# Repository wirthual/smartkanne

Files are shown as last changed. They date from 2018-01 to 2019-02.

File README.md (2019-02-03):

# SmartKanne [smaːɐ̯tˈkanə]

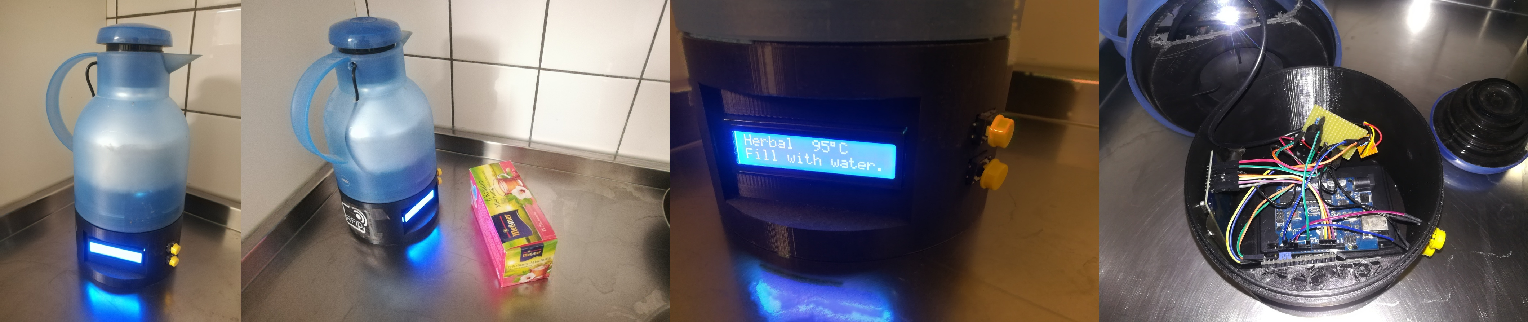
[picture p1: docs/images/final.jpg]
final image sprite


### 1. Introduction
This project was created for the Ubiquitous Computing Course at the Karlsruhe Institute of Technology. The goal of this course is to learn about the development process of a smart appliance. Topics covered in this course are techniques for finding a good idea, analyse your potential customers, sketching methods as well as the technical part like hardware including sensors, actuators and knowledge about arduino.

#### 1.1 Project structure
| Folder | Content |
|:---|:--- |
| README.md | This file. Information about the project in github flavoured markup ([GFM](https://github.github.com/gfm/) )|
| src/ | Contains source code for uploading to arduino|
| docs/schema/ | Contains schema of the electrocins and bill of material. Created with [Fritzing](http://fritzing.org/home/) |
| docs/sketches/ |Contains images of the sketches that were made in the project planning |
|docs/state_diagram/| Contains the state diagram of the finite state machine used in this project. Created with [Dia](https://wiki.gnome.org/Apps/Dia) 
| docs/housing/ | Contains a enlargement for the housing of the tea pot. The .slt file can be printed with a 3D-printer. Created with [FreeCAD](https://www.freecadweb.org/?lang=de).  Also an [image](http://www.rfidsign.eu/html/graphics.html) to indicate the RFID capability is included.  |
| docs/misc/ | Contains a Business model plan as well as a cost estimation made with COSYSMO. 

### 2. Project idea
The idea for this problem came to me during the winter months drinking a lot of tea. However, every time I made a tea I forgot to take the tea bags out of the pot so very often the tea became bitter in the end.
I want to solve this problem by developing this SmartKanne. This device should help me not to forget about my tea. Also it should be able to give me instructions about the right temperature and time for each tea to get the best possible result when steeping tea.

### 3. Requirements
Here I list the basic requierements SmartKanne should be able to cover:

| Requirement | Description |
|:---|:--- |
|Tea selection|The user should be able to select the type of tea he wants to make|
|Tea information|Depending on the type of tea, SmartKanne should know the recommended temperature as well as the steep time |
|Notification|If the tea is ready to drink, SmartKanne should be able to notify to the user |
|Monitor process|In order to let the user know about the progress of his tea, SmartKanne should be able to give feedback to the user about the process|
|Mobile|The device should be able to be carried around while the tea is in progress, so there is no need to wait at a certain point.|

### 4. Designs
In order to cover the features from section 3, SmartKanne needs some additional hardware to fullfill the requierements. In this section I show you some sketches I made in the development process.

#### 4.1 Use Smartphone as user interface
One idea to satisfy the requirements is to control SmartKanne by a smartphone which can communicate over bluetooth low energy or  wifi or something similar. This would have the advantage to allow a lot of settings for the smart kanne, since you have an full interface with all possible UI elements.

sketch smartphone

#### 4.2 Standalone
Onaother possibility to create the user interface for SmartKanne is to use additional hardware. This design allows the gadget to be used independently from other devices and lowers the complexity of usage. Furthermore external sources of errors are excluded. For the power supply there has to be an battery pack included to ensure a convenient usage of the device.

sketch standalone

#### 4.3 Base station
Design number 3 is an approach without external devices as well. However, the idea here is to put all the electronics in an base station where you can put an pot that is then connected automatically. This way multiple pots could be used with one base station(multi user support with multiple pots). The pot would then just include the temerature sensor which would be connected when the pot is put into the station. The disadvantage is that you have to wait till the tea is done to take the pot with you and leave the station behind. Then the base station could be powered by an outlet since it will be stationary anyway. 

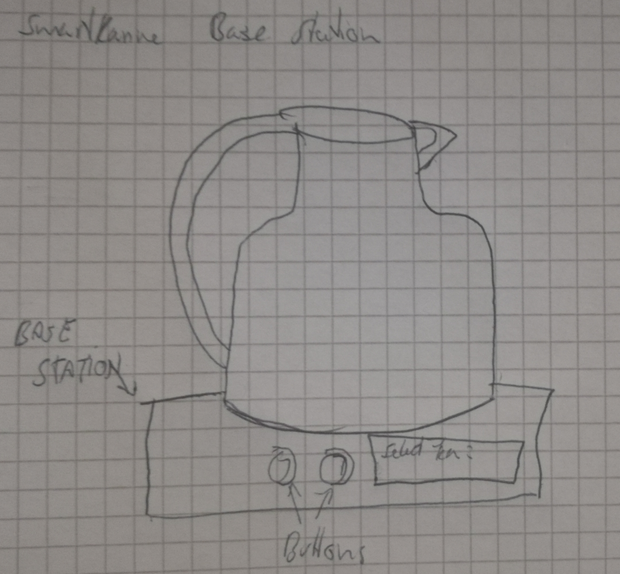
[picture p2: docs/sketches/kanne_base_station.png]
sketch base station


### 5. Design Decision 
In order to build a n appliance the approch number 4.2 seems the best choice in order to have a big impact in the process of making tea. The limitation of user interaction prevents the device from getting to complex and developing some kind of “feature creep”. 
The usage of an additional smart phone brings a lot of overhead an in total two devices are needed for the process of making tea. The idea with the base station interferes with the idea that you are not bound to a certain place and you can carry the hole device around to the place where you want to enjoy your tea.

### 6. Information about the tea types
In order to steep the right  amount of time, information about the right times are taken from 
[here](https://www.lebensmittellexikon.de/t0002940.php#0) 
### 7. Hardware
In oder to build the device which fulfill the requirements from the table above, additional hardware is needed. In this section you find the bill of materials.

| Amount | Part Type |  Descripiton | Price |
|---|:---|:---| :---|
|1| DS18B20 1-Wire Temperature Sensor|Temperature sensor to measure the current temperature as well as detect if water is in the pot or not|  3,65 € 
|1|Piezo Speaker|Speaker to give accustic feedback to user| 2,10 €
|1|LCD screen|Screen for the user interface of the device|  7,99 € 
|1|LCM1602 IIC|Additional hardware for controlling LCD screen over IIC| (Included in display price)
|1|Arduino Uno (Rev3)|Arduino as the core of the device| 24,00 €
|1|RFID-RC522|RFID Reader to allow automatic tea selection| 9,99 €
|1|220Ω Resistor|Needed for piezo speeker| 0,01€
|1|4.7kΩ Resistor|Needed for temperature sensor| 0,01€
|2|Momentary Switch|Switches to allow user interaction| 0,20€
|1|Battery Holder 6xAA|Power supply. Recommended for Arduino: 7 - 12 Volts| 3,00€
|1|Switch|Like [this](https://www.conrad.de/de/schiebeschalter-250-vac-6-a-2-x-einein-sci-r13-602b-05-1-st-701139.html) to fit into the cutout of the housing| 1,00€
|1|Tea pot | Tea pot as base for smartkanne|15 €
|1|3d-printed housing |PLA consumtion ca. 150g  |ca. 7 €
|**Total:**|||**72,95 €**

### 8. Schema
Shows the general setup and connection of the hardware components.  Created with [Fritzing](http://fritzing.org/home/)

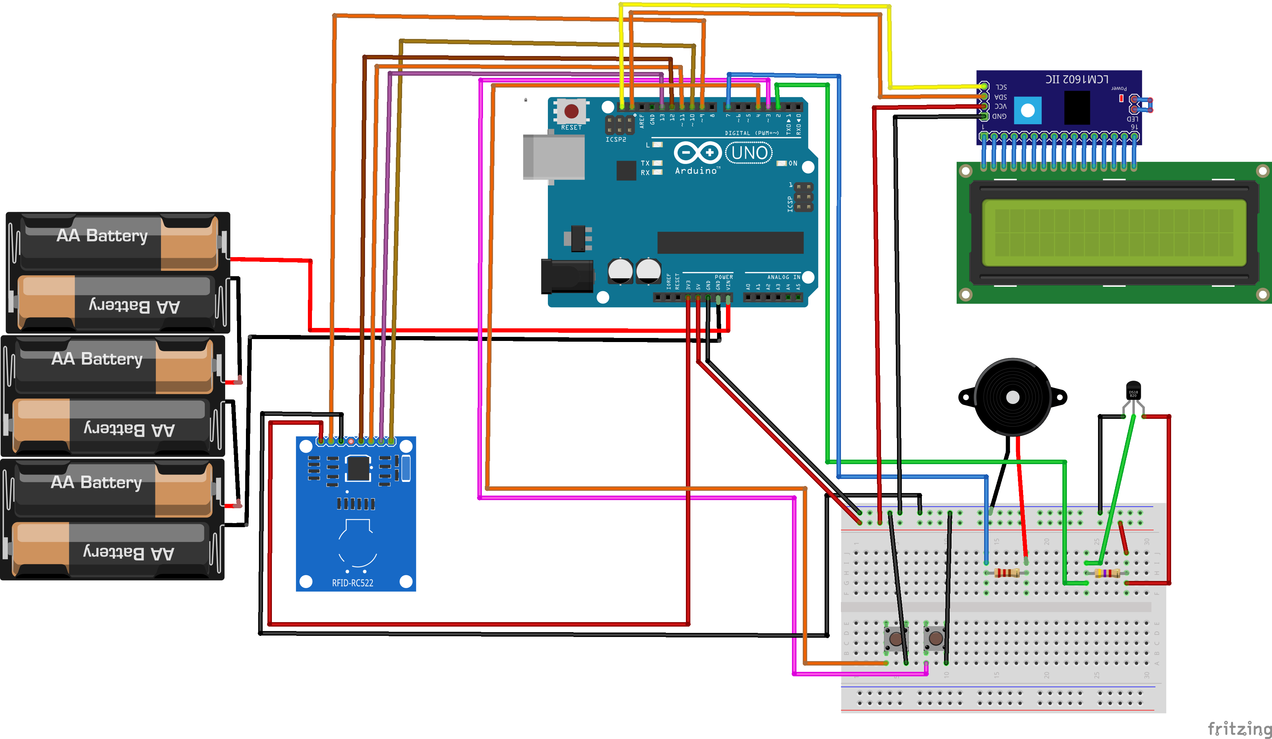
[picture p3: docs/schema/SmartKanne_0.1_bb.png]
schema of project


### 9. Software
The source code can be found in this repository. The basic concept behind it is to use a finite state machine for the general structure of the program. Here you can see the simple structure of the states and its transitions which is then implemented using the [fsm](https://github.com/jonblack/arduino-fsm) library for arduino. For the control of the screen and the rfid reader available libraries are used. 

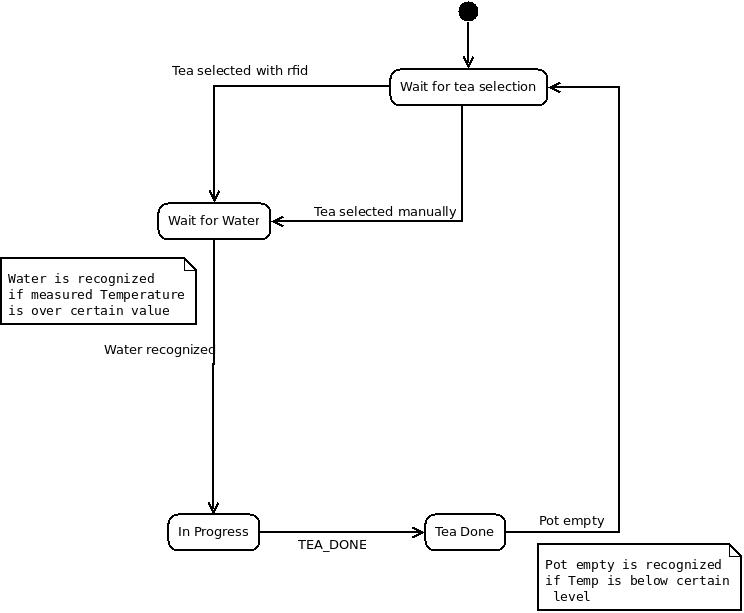
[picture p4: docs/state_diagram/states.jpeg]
states and transitions


### 10. Housing
For the prototype an tea pot like [this](https://www.amazon.de/Emsa-504232-Isolierkanne-Verschluss-Transluzent/dp/B002BWOOYS?th=1)  is used. 

You can easily open up the bottom part and put the cable through the housing in the glass cylinder to measure the temperature. However, then the seiling does not work as expected, thats why the cable is put outside the housing and back into the can from outside. This way the pot does not have to be motified and this approach seems sufficient for a prototype.

For the electronic stuff an enlargement for the pot can be printed. You an find the CAD-model in the folder *docs/housing*. Also an ready-to-print SLT file is included for easy replication. The cutout for the battery holder fits for [this](https://www.amazon.de/Wentronic-Batteriehalter-Mignon-geschlossenes-Geh%C3%A4use/dp/B001C6JTYE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) product. In order to fit, you need to cutoff the clips of the holder a little bit, then it fits nicely into the cutout.

For further improvements you could add a thread to the model and replace the hole bottom of the tea pot to get a nicer product. 

To get an idea about the model you can see the model [here](docs/housing/housing.pdf)

And here is a timelapse of the printing:

timelapse of printing

The full video can be found [here](https://youtu.be/i6MLm4RjLGM)

### 11. Business Model Canvas
In order to get an overview over the business model, here you can see the business model canvas of SmartKanne. It can also be accessed over this [link](https://canvanizer.com/canvas/rdbEy04koZJil).

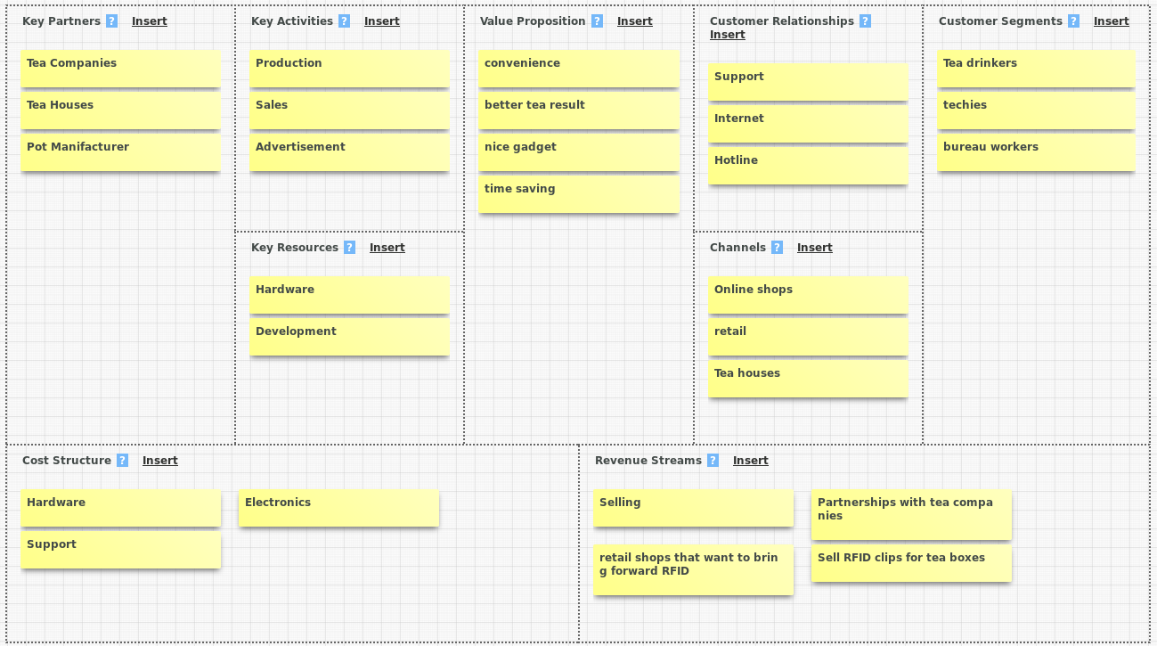
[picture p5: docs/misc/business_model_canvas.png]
business model canvas


### 12. Cost Estimation
The cost estimation of around $13000 for this project was done using [COSYSMO](http://csse.usc.edu/tools/ExpertCOSYSMO.php). 

The full result can be found in this [PDF](docs/misc/Smartkanne_COSYSMO.pdf)

### 13. Possible Improvements
* In order to avoid a too long steep time, there could be a motor to pull out the tea bags as soon as the tea is ready.
* Energy harvesting from the heat of the water
* By now, the time starts as soon as the water temperature is over a certain threshold. However, if the water temparature is to high or to low for the selected kind of tea there is no warning by now. This behaviour could improve overall tea quality.
* Think about getting the right steep time per tea automatically from the internet depending on scanned [EPC](https://www.epc-rfid.info/). Starting point could be *product markup language* [PML](http://web.mit.edu/mecheng/pml/overview.htm), especially so called [Controls](http://web.mit.edu/mecheng/pml/spec_control.htm) to allow a product to communicate with devices. This would require additional internet connection for the tea pot which would then be a part of the IoT.
* Think about an concept to store additional information right on the RFID tag of the product to give additional information for the customer without needing an internet connection as stated before.(e.g Best Before, Recommended Temerature,etc.) This way customers could also benefit directly from the usage of rfid in retail stores without needing an internet connection for every product. Most of literature only focuses on benefits for retailers or the supply chain, not directly for customers. 
Here some examples:
	* Article in [Forbes](https://www.forbes.com/sites/barbarathau/2017/05/15/is-the-rfid-retail-revolution-finally-here-a-macys-case-study/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) about Macys 
	* White Paper about the [State of RFID](https://www.beacontree.net/wp-content/uploads/2017/12/Auburn-state-of-rfid-2016-white-paper.pdf) in apparel shops
	* [Rfid in retail Study 2016](http://webcache.googleusercontent.com/search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) (only accessible through google cache)
	* [BENEFITS AND RISKS OF RFID TECHNOLOGY IN RETAIL FROM THE YOUNGER CUSTOMERS POINT OF VIEW](https://hrcak.srce.hr/ojs/index.php/plusm/article/download/3871/2258) 
	* [EPC/RFID – Die Zukunft hat begonnen ](https://www.gs1-germany.de/fileadmin/gs1/basis_informationen/epc_rfid_die_zukunft_hat_begonnen.pdf)

* By now, the only way the user is notified is over an audio signal (beeping). Think about using blinking or haptic as well for impaired people
* Think about measuring the amount of tea, this way Smartkanne could provide extensive statistics about the consum of a user for the quantified self

### 14. Further Information
##### Rough Lifetime estimation (very conservative):
Power consumption:

| Part | Consumption | 
|---|:---|
| [LCD](https://www.sparkfun.com/datasheets/LCD/GDM1602K.pdf) | 4mA + 160mA with Backlight
| [RFID](https://www.nxp.com/docs/en/data-sheet/MFRC522.pdf) | 100mA
|[Temperature Sensor](https://datasheets.maximintegrated.com/en/ds/DS18B20.pdf) | 1mA
|[Buuzzer](https://www.cui.com/product/resource/cem-1203-42-.pdf) |  35mA
|[Arduino](https://store.arduino.cc/arduino-uno-rev3) | 50 mA
|**Overall**| **ca. 300mA**

Alkaline Batteries AA: ca. 2100mAh

Lifetime in use: 2100mAh/300mA = 7h

Time per Usage: 10min (Longest tea needs 8 minutes + 2 minutes buffer)

Approx. usages per battery load: (7*60min)/10min = 42 usages

With around 1,5 usages a day: Lifetime around 28 days

Note: Turning off the backlight of the display will double the lifetime. Also lot of power savingwith RFID reader is possible (see [this](https://github.com/miguelbalboa/rfid/issues/269))

##### Market Research:
Accoding to [this](https://www.statista.com/statistics/326384/global-tea-beverage-market-size/) statistics, the global global tea beverage market is growing constantly and will reach 44.3 billion USD in 2021.

As relation, the [Global TV market revenue](https://www.statista.com/statistics/461324/global-tv-market-sales/) in 2017 was estimated to 105 billion USD. 

##### Similar Products:
[the Smart Tea Pot™](https://sageappliances.co.uk/products/the-sage-smart-tea-pot?variant=52066480708)  £129.95 (01.03.2018)

[the Tea Maker](https://sageappliances.co.uk/collections/tea-makers/products/the-one-touch-tea-maker?variant=40399807556)  £199.95 (01.03.2018) 
in the [YouTube-Video](https://youtu.be/JXULYQFoPrc?t=3m6s) he says: "...its the only one in the world..."but wait: 
[the Tea Maker™](https://www.brevilleusa.com/products/the-one-touch-tea-maker?variant=33819867281) 249$ (01.03.2018) 

[qiaerista](https://qiaerista.com/) / [Campain on Kickstarter](https://www.kickstarter.com/projects/rickha/qi-aerista-the-ultimate-wi-fi-enabled-smart-tea-ma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) $200 (01.03.2018)

[sketch1]: docs/sketches/kanne_smartphone.png "Sketch from SmartKanne with Smartphone"
[sketch2]: docs/sketches/kanne_standalone.png "Sketch from SmartKanne Standalone"
[sketch3]: docs/sketches/kanne_base_station.png "Sketch from SmartKanne with base station"
[schema]: docs/schema/SmartKanne_0.1_bb.png "Schema from SmartKanne"
[states]: docs/state_diagram/states.jpeg "State diagram" 
[bmc]: docs/misc/business_model_canvas.png "Business Model Canvas" 
[print]: docs/housing/printing.gif  "3d printing of housing timelapse"
[final1]: docs/images/final.jpg "Image sprite of the final product"

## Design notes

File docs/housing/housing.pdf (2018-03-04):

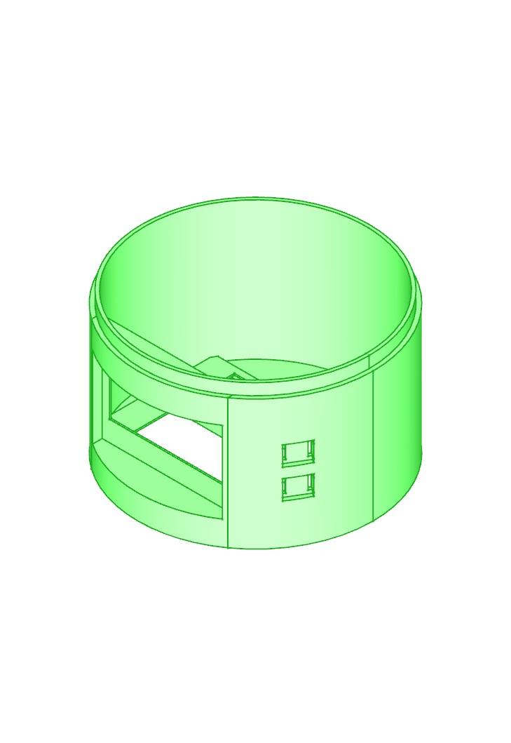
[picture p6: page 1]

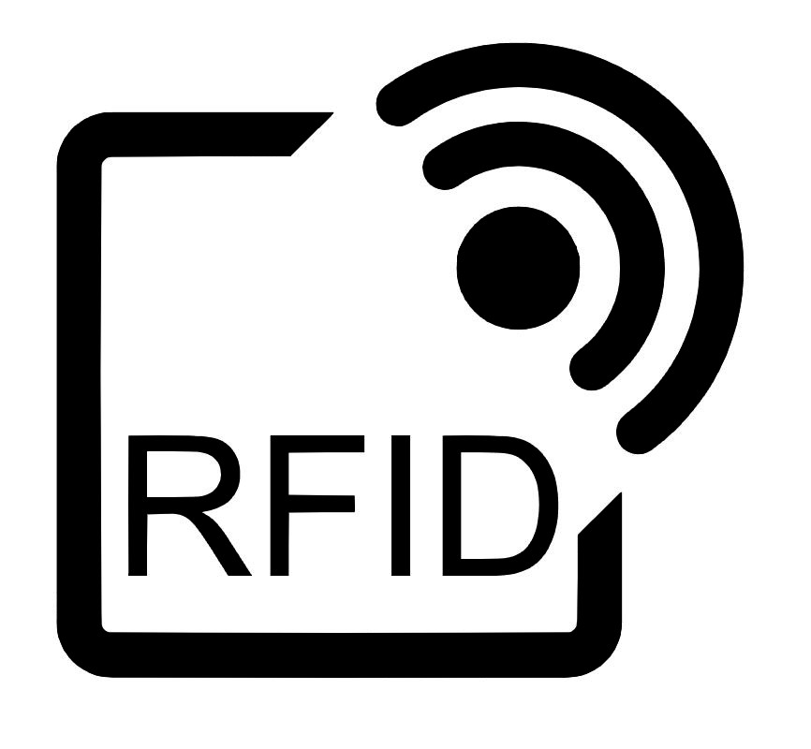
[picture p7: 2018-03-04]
docs/housing/RFID.jpg

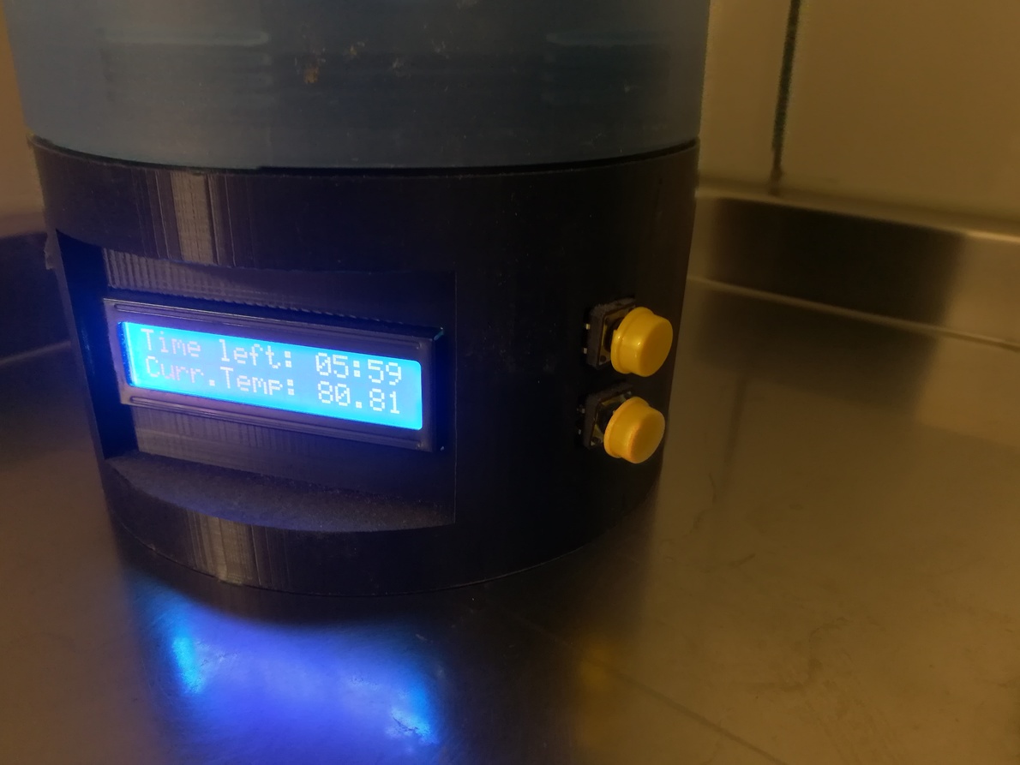
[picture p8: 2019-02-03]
docs/images/smartkanne5.jpg

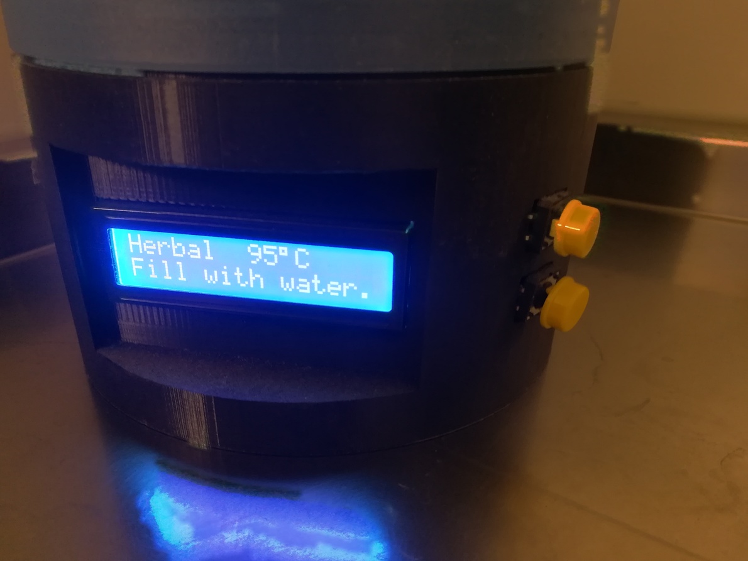
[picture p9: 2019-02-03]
docs/images/smartkanne3.jpg

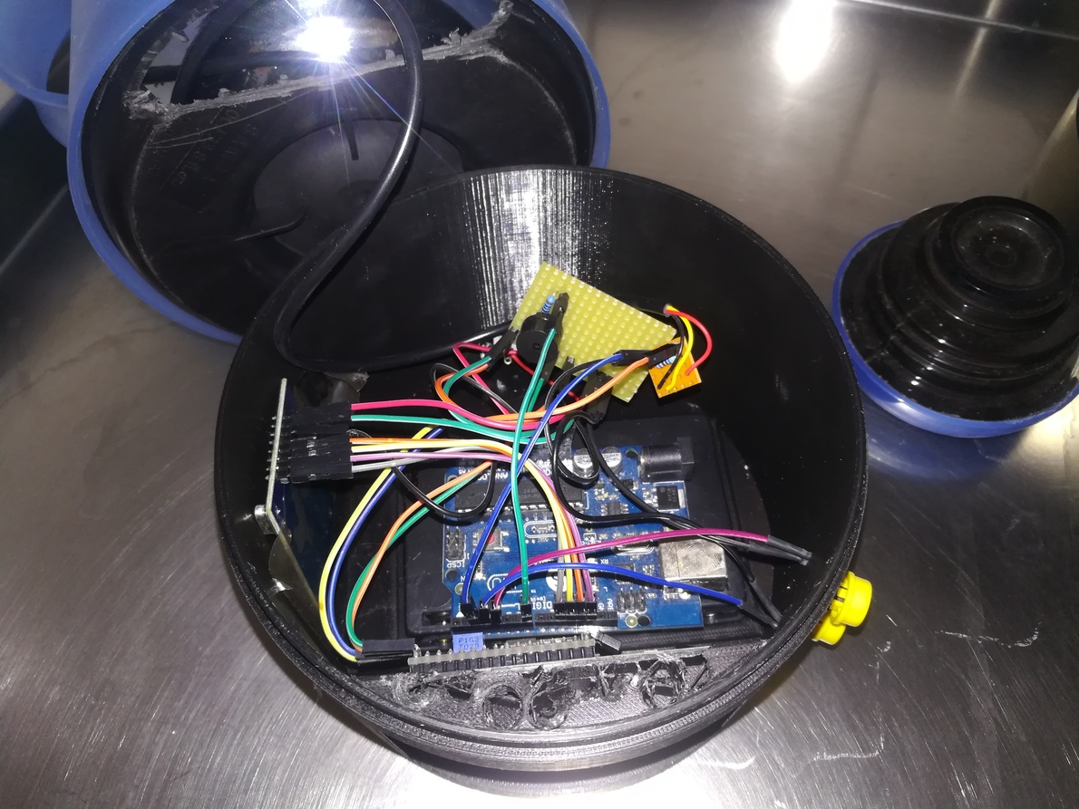
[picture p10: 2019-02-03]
docs/images/smartkanne4.jpg

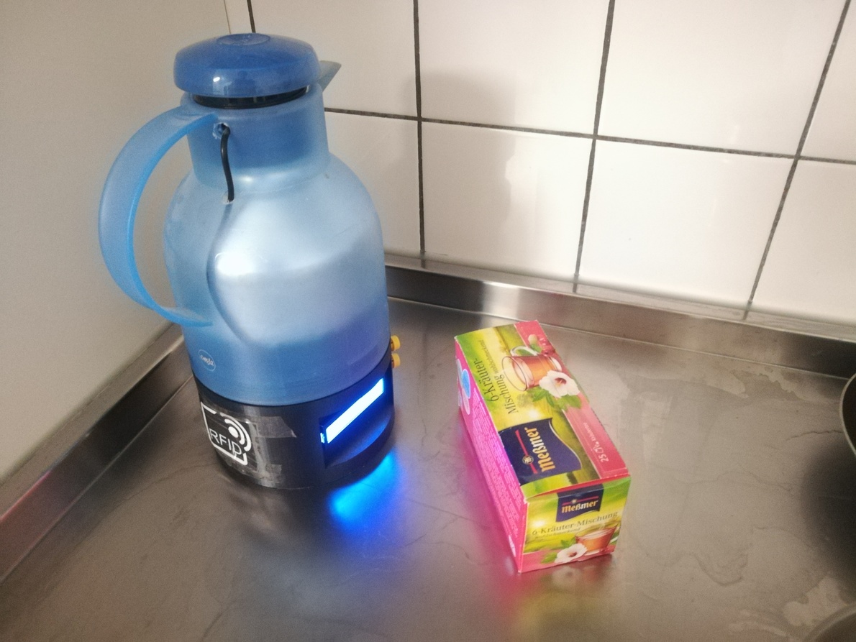
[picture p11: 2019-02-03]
docs/images/smartkanne2.jpg

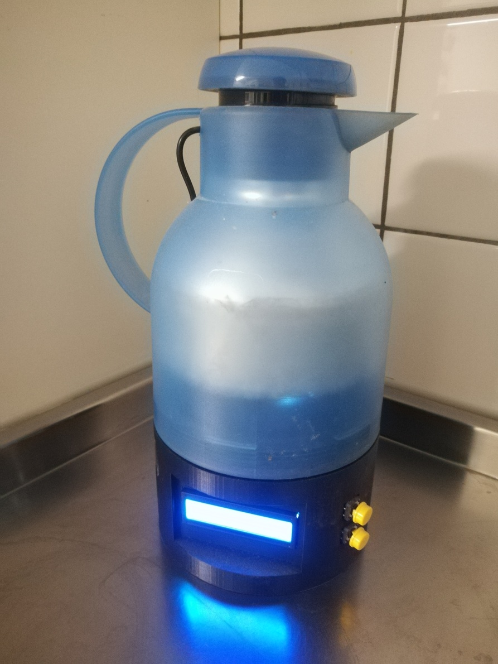
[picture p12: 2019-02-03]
docs/images/smartkanne1.jpg

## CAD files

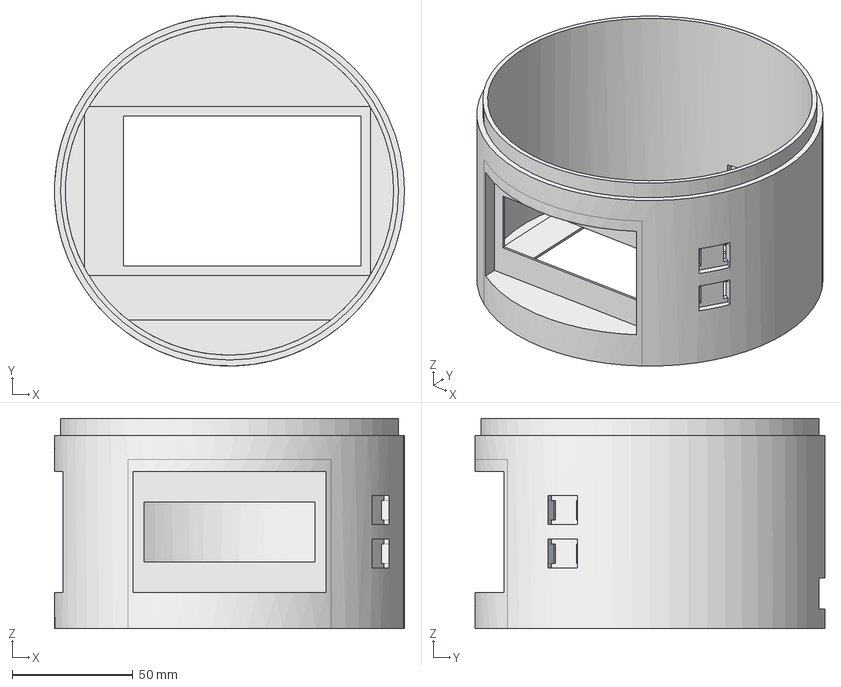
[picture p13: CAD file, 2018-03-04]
docs/housing/housing.fcstd
145.0 x 145.0 x 87.0 mm

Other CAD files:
docs/housing/housing.stl

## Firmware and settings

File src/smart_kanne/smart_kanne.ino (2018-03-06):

#include <Fsm.h>
#include <MFRC522.h>
#include <LiquidCrystal_I2C.h> // Using version 1.3.5
#include <DallasTemperature.h>
#include <OneWire.h>
#include <CountDown.h>
#include "Tea.h"

//Version printed in splashscreen
const String vers = "v0.10";

//general pins
#define BUTTON_PIN_1 4
#define BUTTON_PIN_2 3
#define BUZZER_PIN 7

//pins for temp sensor
#define ONE_WIRE_BUS 2

//pins for rfid reader
#define RST_PIN 9
#define SS_PIN 10

// Create MFRC522 instance
MFRC522 mfrc522(SS_PIN, RST_PIN);

//Create instance for temp sensors
OneWire oneWire(ONE_WIRE_BUS);
DallasTemperature sensors(&oneWire);

// The LCD constructor - address shown is 0x27 - may or may not be correct for yours
// Also based on YWRobot LCM1602 IIC V1
LiquidCrystal_I2C lcd(0x27, 2, 1, 0, 4, 5, 6, 7, 3, POSITIVE);

//Create Countdown
CountDown CD(CountDown::SECONDS);

#define NUMBER_OF_TEAS 7 // Configurable, see typical pin layout above
Tea teas[NUMBER_OF_TEAS];
Tea currentTea = Tea();

//Events for state machine transitions
#define TEA_SELECTED_EVENT 0
#define WATER_RECOGNIZED_EVENT 1
#define TEA_DONE_EVENT 2
#define RESTART_EVENT 3

/* state_wait_for_tea_selection: Wait till user selects type of tea. Eighter via buttons or rfid reader
   state_wait_for_water:         Wait till water is in pot.(Temperature bigger than x)
   state_in_progress:            Wait till time is over
   state_done                    Wait till pot is empty and show current temperature.
*/
State state_wait_for_tea_selection(&state_wait_for_tea_selection_enter, &state_wait_for_tea_selection_exit, NULL);
State state_wait_for_water(&state_wait_for_water_enter, &state_wait_for_water_exit, NULL);
State state_in_progress(&state_in_progress_enter, &state_in_progress_exit, NULL);
State state_done(&state_done_enter, &state_done_exit, NULL);
Fsm fsm(&state_wait_for_tea_selection);

//Global variables
int counter = 0;
bool teaSelected = false;
int button1Old = HIGH;
int button2Old = HIGH;
void setup()
{
  //Inizialize LCD Display
  lcd.begin(16, 2); // sixteen characters across - 2 lines
  lcd.backlight();

  //Show splashscreen  on startup
  showSplashScreen(vers);

  //Initialize serial communication
  Serial.begin(9600);

  //Setup pins of buttons and buzzer
  pinMode(BUTTON_PIN_1, INPUT_PULLUP);
  pinMode(BUTTON_PIN_2, INPUT_PULLUP);
  pinMode(BUZZER_PIN, OUTPUT); // Set buzzer - pin 9 as an output

  //Initialize temp sensor
  sensors.begin();

  //Initialize RFID reader
  SPI.begin();
  mfrc522.PCD_Init();

  //Initialize Teas
    Tea blackTea = Tea("Black",300,95,-1);
    Tea greenTea = Tea("Green",240,80,-1);
    Tea oolongTea = Tea("Oolong",60,85,-1);
    Tea yellowTea = Tea("Yellow",180,75,-1);
    Tea whiteTea = Tea("White",240,70,-1);
    Tea herbalTea = Tea("Herbal",420,95,10035);
    Tea fruitTea = Tea("Fruit",480,95,4294957801);
  //Tea blackTea = Tea("Black", 10, 95, 4294957801);
  //Tea greenTea = Tea("Green", 11, 80, 10035);
  //Tea oolongTea = Tea("Oolong", 5, 85, -1);
  //Tea yellowTea = Tea("Yellow", 6, 75, -1);
  //Tea whiteTea = Tea("White", 7, 70, -1);
  //Tea herbalTea = Tea("Herbal", 8, 95, -1);
  //Tea fruitTea = Tea("Fruit", 9, 95, -1);

  teas[0] = blackTea;
  teas[1] = greenTea;
  teas[2] = oolongTea;
  teas[3] = yellowTea;
  teas[4] = whiteTea;
  teas[5] = herbalTea;
  teas[6] = fruitTea;

  currentTea = teas[0];

  //Init transitions
  fsm.add_transition(&state_wait_for_tea_selection, &state_wait_for_water, TEA_SELECTED_EVENT, NULL);
  fsm.add_transition(&state_wait_for_water, &state_in_progress, WATER_RECOGNIZED_EVENT, NULL);
  fsm.add_transition(&state_in_progress, &state_done, TEA_DONE_EVENT, NULL);
  fsm.add_transition(&state_done, &state_wait_for_tea_selection, RESTART_EVENT, NULL);


  //Delay so splashscrren stays for some time
  delay(2000);

}

void loop()
{
  // Call fsm run
  fsm.run_machine();
  delay(50);
}

//Functions called from state machine when new state is entered or exited
void state_wait_for_tea_selection_enter()
{
  //Initial state: reset all global variables
  counter = 0;
  teaSelected = false;
  currentTea = teas[0];
  button1Old = HIGH;
  button2Old = HIGH;

  Serial.println("state_initial_enter");
  lcd.clear();
  lcd.setCursor(0, 0);
  lcd.print("Select your");
  // 8th character - 2nd line
  lcd.setCursor(0, 1);
  lcd.print("type of tea.");
  lcd.display();
}

void state_wait_for_tea_selection_exit()
{
  Serial.println("state_wait_for_tea_selection_exit");

  //read the pushbutton value into a variable
  int button1State = digitalRead(BUTTON_PIN_1);
  int button2State = digitalRead(BUTTON_PIN_2);
  //print out the value of the pushbutton

  //Select Button
  if (button1State != button1Old) {
    button1Old = LOW;
    if (button1State == LOW) {
      Serial.println("Button pressed!");
    }
    else {
      Serial.println("Button released!");
      if (counter == NUMBER_OF_TEAS) {
        counter = 0;
      }
      currentTea = teas[counter];
      teaSelected = true;
      counter = counter + 1;
      printTeaInfo(currentTea);
      button1Old = HIGH;
    }
  }

  //Enter Button
  if (button2State != button2Old) {
    button2Old = LOW;
    if (button2State == LOW) {
      Serial.println("Button2 pressed!");
    }
    else {
      Serial.println("Button2 released!");
      button2Old = HIGH;
      Serial.println(teaSelected);
      if (teaSelected == true) {
        fsm.trigger(TEA_SELECTED_EVENT);
      }
      else {
        lcd.clear();
        lcd.setCursor(0, 0);
        lcd.print("Select tea first!");
        lcd.display();
      }
    }
  }

  //RFID Cards
  if (mfrc522.PICC_IsNewCardPresent()) {
    unsigned long uid = getID();
    if (uid != -1) {
      Serial.print("Card detected, UID: ");
      Serial.println(uid);
      for (int i = 0; i < NUMBER_OF_TEAS; i = i + 1) {
        Serial.println(teas[i].getUid());
        if (uid == teas[i].getUid()) {
          currentTea = teas[i];
          teaSelected = true;
          printTeaInfo(currentTea);
          tone(BUZZER_PIN, 1000);
          delay(500);
          noTone(BUZZER_PIN);
          fsm.trigger(TEA_SELECTED_EVENT);
          break;
        }
      }
    }
  }
}

void state_wait_for_water_enter()
{
  Serial.println("state_wait_for_water_enter");
  lcd.clear();
  lcd.setCursor(0, 0);
  lcd.print(currentTea.getName());
  lcd.setCursor(8, 0);
  lcd.print(currentTea.getTempC());
  lcd.print((char)223);
  lcd.print("C");

  lcd.setCursor(0, 1);
  lcd.print("Fill with water.");
  lcd.display();
}

void state_wait_for_water_exit()
{
  Serial.println("state_wait_for_water_exit");
  if (getTemperature() >= 65.0) {
    fsm.trigger(WATER_RECOGNIZED_EVENT);
  }
  /* Possible improvement: What if water is to cold or to hot?
    //If water temperature is under recommendet temperature, start immediately
    if (getTemperature() <= currentTea.getTempC()) {
      fsm.trigger(WATER_RECOGNIZED_EVENT);
    }
    //If water temperature is higher, wait till it cools down
    if(getTemperature()> currentTea.getTempC()){
      //Notification: Water to hot.
    }*/
}

void state_in_progress_enter()
{
  Serial.println("state_in_progress_enter");
  lcd.clear();
  lcd.setCursor(0, 0);
  lcd.print("Time left: ");

  lcd.setCursor(0, 1);
  lcd.print("Curr.Temp:");
  lcd.setCursor(11, 1);
  lcd.print(getTemperature());
  lcd.display();

  CD.start(currentTea.getTimeSec());
}

long previousMillis = 0;
long interval = 1000;
void state_in_progress_exit()
{
  Serial.println("state_in_progress_exit");
  unsigned long currentMillis = millis();
  if (currentMillis - previousMillis > interval) {
    previousMillis = currentMillis;
    Serial.println("Time left:");
    Serial.println(CD.remaining());
    if (CD.remaining() == 0) {
      fsm.trigger(TEA_DONE_EVENT);
    }
    else {
      updateProcessNotification(CD.remaining());
    }
  }
}

void state_done_enter()
{
  Serial.println("state_done_enter");
  teaDone();
  lcd.setCursor(0, 1);
  lcd.print("Cur.Temp: ");
}

void state_done_exit()
{
  Serial.println("state_done_exit");
  lcd.setCursor(11, 1);
  lcd.print(getTemperature());
  lcd.display();
  delay(5000); //Update tea every 5 seconds
  if (getTemperature() < 30.00) {
    fsm.trigger(RESTART_EVENT);
  }
}

void showSplashScreen(String vers)
{
  lcd.clear();
  lcd.setCursor(0, 0);
  lcd.print("Welcome to");
  // 8th character - 2nd line
  lcd.setCursor(0, 1);
  lcd.print("SmartKanne " + vers);
  lcd.display();
}

void updateProcessNotification(long time)
{
  lcd.setCursor(11, 0);
  int minutes = (time / 60) % 60;
  int seconds = time % 60;
  if (minutes < 10)
    lcd.print("0");
  lcd.print(minutes);
  lcd.print(":");
  if (seconds < 10)
    lcd.print("0");
  lcd.print(seconds);

  lcd.setCursor(11, 1);
  lcd.print(getTemperature());
  lcd.display();
}

void printTeaInfo(Tea tea)
{
  lcd.clear();
  lcd.setCursor(0, 0);
  lcd.print(tea.getName());
  lcd.setCursor(8, 0);
  lcd.print(tea.getTempC());
  lcd.print((char)223);
  lcd.print("C");

  lcd.setCursor(0, 1);
  lcd.print("Time: ");
  int minutes = (tea.getTimeSec() / 60) % 60;
  int seconds = tea.getTimeSec() % 60;
  if (minutes < 10)
    lcd.print("0");
  lcd.print(minutes);
  lcd.print(":");
  if (seconds < 10)
    lcd.print("0");
  lcd.print(seconds);
}

void teaDone()
{
  lcd.clear();
  lcd.setCursor(2, 0);
  lcd.print("Tea is ready!");
  lcd.setCursor(4, 1);
  lcd.print("Enjoy.");
  lcd.display();

  tone(BUZZER_PIN, 1000);
  delay(1000);
  noTone(BUZZER_PIN);
  delay(1000);
  tone(BUZZER_PIN, 1000);
  delay(1000);
  noTone(BUZZER_PIN);
  delay(1000);
  tone(BUZZER_PIN, 1000);
}

//From https://stackoverflow.com/questions/32839396/how-to-get-the-uid-of-rfid-in-arduino
/**
   mfrc522.PICC_IsNewCardPresent() should be checked before
   @return the card UID
*/
unsigned long getID()
{
  if (!mfrc522.PICC_ReadCardSerial()) { //Since a PICC placed get Serial and continue
    return -1;
  }
  unsigned long hex_num;
  hex_num = mfrc522.uid.uidByte[0] << 24;
  hex_num += mfrc522.uid.uidByte[1] << 16;
  hex_num += mfrc522.uid.uidByte[2] << 8;
  hex_num += mfrc522.uid.uidByte[3];
  mfrc522.PICC_HaltA(); // Stop reading
  return hex_num;
}

float getTemperature()
{
  sensors.requestTemperatures(); // Send the command to get temperature readings
  float temp = sensors.getTempCByIndex(0);
  Serial.println(temp);
  return temp;
}

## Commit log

2018-03-04 Done improvements of code. Added code for temparature sensor and water recognition. Improvements on business model plan. Calculation of lifetime as well as market research and gif of 3d printing as w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
    [SmartKanne_0.1.fzz, basic_base.fcstd, housing.fcstd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]
2018-03-04 Removed problematic part of cad design. Edited readme for better readability.
    [housing.fcstd, housing.stl]
2018-03-06 Further improvements of readme. Added links. Added folder structure for arduino code.
    [SmartKanne_0.1.fzz]
